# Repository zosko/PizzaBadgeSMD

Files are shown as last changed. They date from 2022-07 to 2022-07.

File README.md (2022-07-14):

# Pizza Badge

8 Slices pizza badge presented with LEDs. Slices will light when they receive response from server how many points you have.

## Scheme
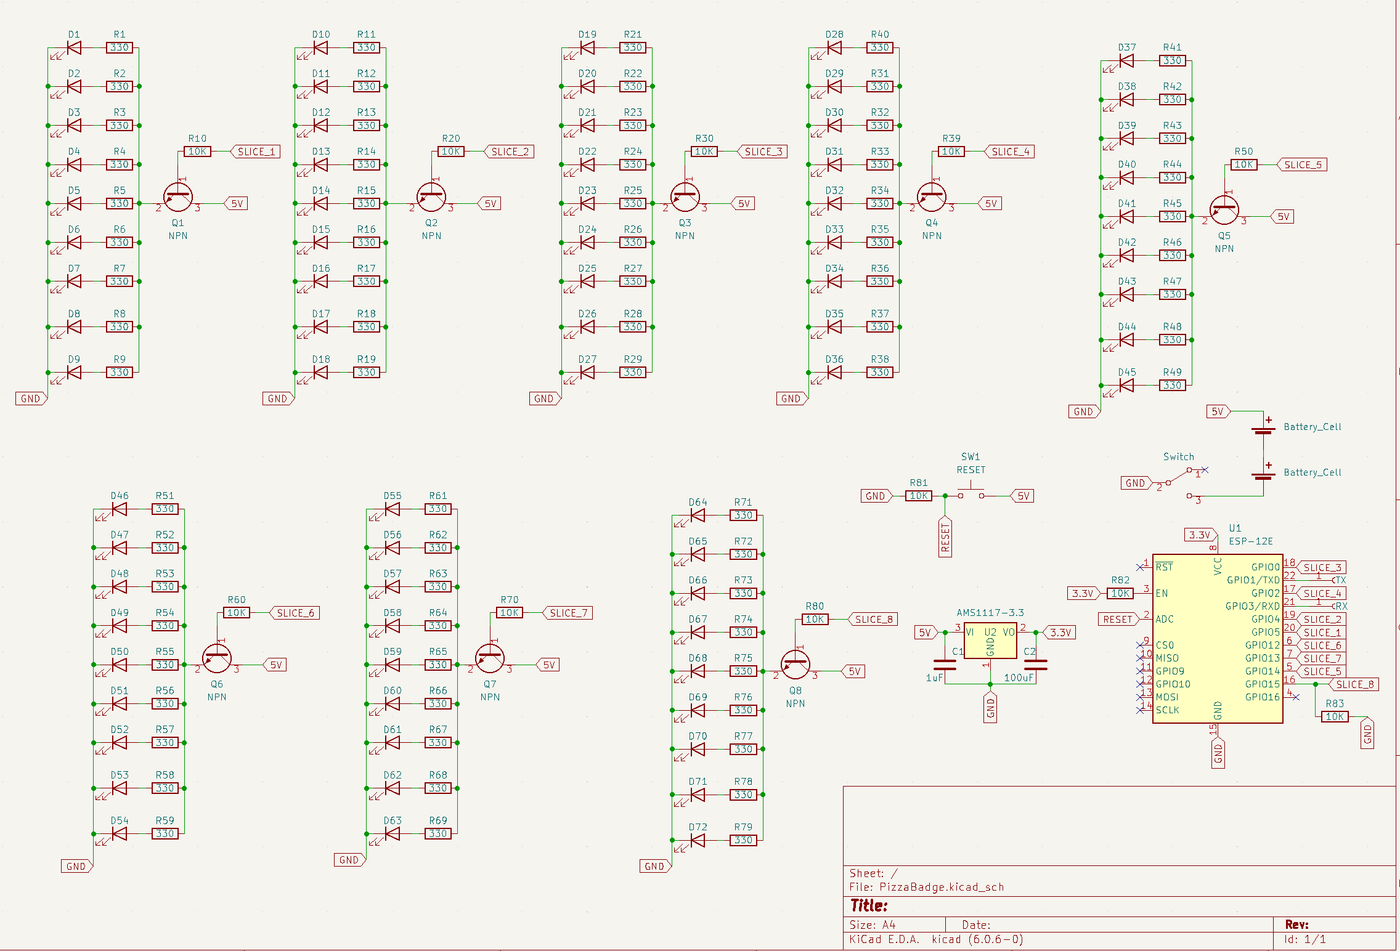
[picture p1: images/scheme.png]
Scheme


## Board
Board

## PCB Design

For PCB design i will use services from SeeedFusion. 

Seeed Fusion PCB Assembly Service offers one-stop prototyping for PCB manufacture, PCB assembly and as a result they produce superior quality PCBs and Fast Turnkey PCBA from 7 working days. When you prototype with Seeed Fusion, they can definitely provide Free DFA and Free functional tests for you! 

Check out their website to know about their manufacturing capabilities and service.
https://www.seeedstudio.com/prototype-pcb-assembly.html 

## Reasons to choose Seeed Studio
- They provide PCB services at extremely low pricing and with excellent quality.
- Their offer is structured in such a way that everyone may have these boards at a reasonable price.
- They have a highly knowledgeable crew that leads their clients to avail deals and guides them about the costs and rates of different services.
- A four-layer board with a comparable feature costs $5 for 10 pieces and is made in four days.
- SMT stencil with size (10cm x 13cm) is available for $8.00 per piece.

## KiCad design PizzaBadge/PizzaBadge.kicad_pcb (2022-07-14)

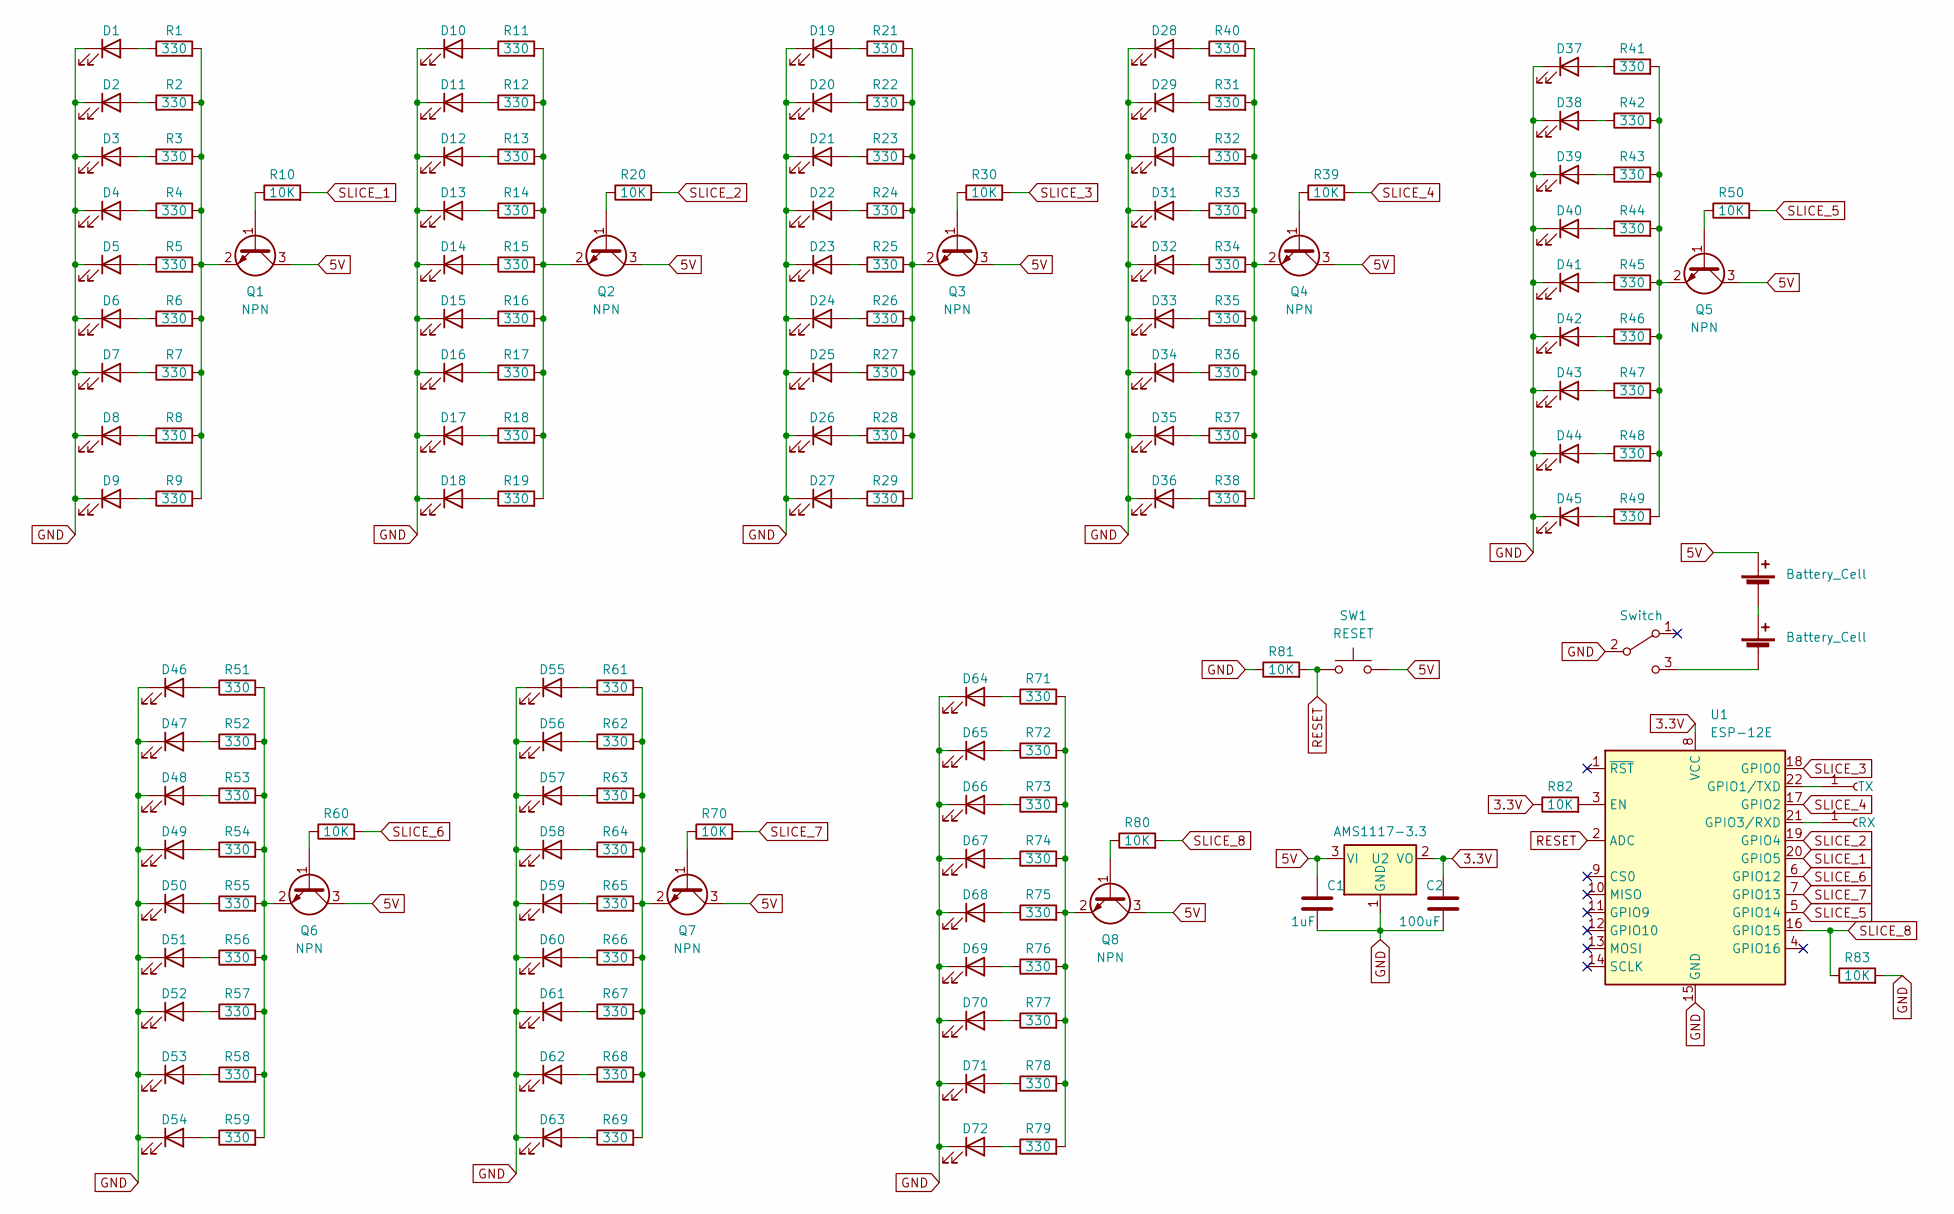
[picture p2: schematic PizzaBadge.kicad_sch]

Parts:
BT1, BT2: Battery_Cell; BatteryHolder_Keystone_3000_1x12mm
C1: 1uF; C_0805_2012Metric
C2: 100uF; C_0805_2012Metric
D1, D2, D3, D4, D5, D6, D7, D8, D9, D10, D11, D12, D13, D14, D15, D16, D17, D18, D19, D20, D21, D22, D23, D24, D25, D26, D27, D28, D29, D30, D31, D32, D33, D34, D35, D36, D37, D38, D39, D40, D41, D42, D43, D44, D45, D46, D47, D48, D49, D50, D51, D52, D53, D54, D55, D56, D57, D58, D59, D60, D61, D62, D63, D64, D65, D66, D67, D68, D69, D70, D71, D72: LED; LED_0805_2012Metric
J1: TX; TestPoint_Pad_2.0x2.0mm
J2: RX; TestPoint_Pad_2.0x2.0mm
Q1, Q2, Q3, Q4, Q5, Q6, Q7, Q8: NPN; SOT-23
R1, R2, R3, R4, R5, R6, R7, R8, R9, R11, R12, R13, R14, R15, R16, R17, R18, R19, R21, R22, R23, R24, R25, R26, R27, R28, R29, R31, R32, R33, R34, R35, R36, R37, R38, R40, R41, R42, R43, R44, R45, R46, R47, R48, R49, R51, R52, R53, R54, R55, R56, R57, R58, R59, R61, R62, R63, R64, R65, R66, R67, R68, R69, R71, R72, R73, R74, R75, R76, R77, R78, R79: 330; R_0805_2012Metric
R10, R20, R30, R39, R50, R60, R70, R80, R81, R82, R83: 10K; R_0805_2012Metric
SW1: RESET; SW_SPST_CK_RS282G05A3
SW2: Switch; SW_SPDT_PCM12
U1: ESP-12E
U2: AMS1117-3.3; SOT-223-3_TabPin2

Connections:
3.3V: C2.1, R82.1, U1.8 (VCC), U2.2 (VO)
5V: BT1.1 (+), C1.1, Q1.3 (C), Q2.3 (C), Q3.3 (C), Q4.3 (C), Q5.3 (C), Q6.3 (C), Q7.3 (C), Q8.3 (C), SW1.2, U2.3 (VI)
GND: C1.2, C2.2, D1.1 (K), D2.1 (K), D3.1 (K), D4.1 (K), D5.1 (K), D6.1 (K), D7.1 (K), D8.1 (K), D9.1 (K), D10.1 (K), D11.1 (K), D12.1 (K), D13.1 (K), D14.1 (K), D15.1 (K), D16.1 (K), D17.1 (K), D18.1 (K), D19.1 (K), D20.1 (K), D21.1 (K), D22.1 (K), D23.1 (K), D24.1 (K), D25.1 (K), D26.1 (K), D27.1 (K), D28.1 (K), D29.1 (K), D30.1 (K), D31.1 (K), D32.1 (K), D33.1 (K), D34.1 (K), D35.1 (K), D36.1 (K), D37.1 (K), D38.1 (K), D39.1 (K), D40.1 (K), D41.1 (K), D42.1 (K), D43.1 (K), D44.1 (K), D45.1 (K), D46.1 (K), D47.1 (K), D48.1 (K), D49.1 (K), D50.1 (K), D51.1 (K), D52.1 (K), D53.1 (K), D54.1 (K), D55.1 (K), D56.1 (K), D57.1 (K), D58.1 (K), D59.1 (K), D60.1 (K), D61.1 (K), D62.1 (K), D63.1 (K), D64.1 (K), D65.1 (K), D66.1 (K), D67.1 (K), D68.1 (K), D69.1 (K), D70.1 (K), D71.1 (K), D72.1 (K), R81.1, R83.2, SW2.2 (B), U1.15 (GND), U2.1 (GND)
unnamed: BT1.2 (-), BT2.1 (+)
unnamed: BT2.2 (-), SW2.3 (C)
unnamed: D1.2 (A), R1.1
unnamed: D2.2 (A), R2.1
unnamed: D3.2 (A), R3.1
unnamed: D4.2 (A), R4.1
unnamed: D5.2 (A), R5.1
unnamed: D6.2 (A), R6.1
unnamed: D7.2 (A), R7.1
unnamed: D8.2 (A), R8.1
unnamed: D9.2 (A), R9.1
unnamed: D10.2 (A), R11.1
unnamed: D11.2 (A), R12.1
unnamed: D12.2 (A), R13.1
unnamed: D13.2 (A), R14.1
unnamed: D14.2 (A), R15.1
unnamed: D15.2 (A), R16.1
unnamed: D16.2 (A), R17.1
unnamed: D17.2 (A), R18.1
unnamed: D18.2 (A), R19.1
unnamed: D19.2 (A), R21.1
unnamed: D20.2 (A), R22.1
unnamed: D21.2 (A), R23.1
unnamed: D22.2 (A), R24.1
unnamed: D23.2 (A), R25.1
unnamed: D24.2 (A), R26.1
unnamed: D25.2 (A), R27.1
unnamed: D26.2 (A), R28.1
unnamed: D27.2 (A), R29.1
unnamed: D28.2 (A), R40.1
unnamed: D29.2 (A), R31.1
unnamed: D30.2 (A), R32.1
unnamed: D31.2 (A), R33.1
unnamed: D32.2 (A), R34.1
unnamed: D33.2 (A), R35.1
unnamed: D34.2 (A), R36.1
unnamed: D35.2 (A), R37.1
unnamed: D36.2 (A), R38.1
unnamed: D37.2 (A), R41.1
unnamed: D38.2 (A), R42.1
unnamed: D39.2 (A), R43.1
unnamed: D40.2 (A), R44.1
unnamed: D41.2 (A), R45.1
unnamed: D42.2 (A), R46.1
unnamed: D43.2 (A), R47.1
unnamed: D44.2 (A), R48.1
unnamed: D45.2 (A), R49.1
unnamed: D46.2 (A), R51.1
unnamed: D47.2 (A), R52.1
unnamed: D48.2 (A), R53.1
unnamed: D49.2 (A), R54.1
unnamed: D50.2 (A), R55.1
unnamed: D51.2 (A), R56.1
unnamed: D52.2 (A), R57.1
unnamed: D53.2 (A), R58.1
unnamed: D54.2 (A), R59.1
unnamed: D55.2 (A), R61.1
unnamed: D56.2 (A), R62.1
unnamed: D57.2 (A), R63.1
unnamed: D58.2 (A), R64.1
unnamed: D59.2 (A), R65.1
unnamed: D60.2 (A), R66.1
unnamed: D61.2 (A), R67.1
unnamed: D62.2 (A), R68.1
unnamed: D63.2 (A), R69.1
unnamed: D64.2 (A), R71.1
unnamed: D65.2 (A), R72.1
unnamed: D66.2 (A), R73.1
unnamed: D67.2 (A), R74.1
unnamed: D68.2 (A), R75.1
unnamed: D69.2 (A), R76.1
unnamed: D70.2 (A), R77.1
unnamed: D71.2 (A), R78.1
unnamed: D72.2 (A), R79.1
unnamed: Q1.1 (B), R10.1
unnamed: Q1.2 (E), R1.2, R2.2, R3.2, R4.2, R5.2, R6.2, R7.2, R8.2, R9.2
unnamed: Q2.1 (B), R20.1
unnamed: Q2.2 (E), R11.2, R12.2, R13.2, R14.2, R15.2, R16.2, R17.2, R18.2, R19.2
unnamed: Q3.1 (B), R30.1
unnamed: Q3.2 (E), R21.2, R22.2, R23.2, R24.2, R25.2, R26.2, R27.2, R28.2, R29.2
unnamed: Q4.1 (B), R39.1
unnamed: Q4.2 (E), R31.2, R32.2, R33.2, R34.2, R35.2, R36.2, R37.2, R38.2, R40.2
unnamed: Q5.1 (B), R50.1
unnamed: Q5.2 (E), R41.2, R42.2, R43.2, R44.2, R45.2, R46.2, R47.2, R48.2, R49.2
unnamed: Q6.1 (B), R60.1
unnamed: Q6.2 (E), R51.2, R52.2, R53.2, R54.2, R55.2, R56.2, R57.2, R58.2, R59.2
unnamed: Q7.1 (B), R70.1
unnamed: Q7.2 (E), R61.2, R62.2, R63.2, R64.2, R65.2, R66.2, R67.2, R68.2, R69.2
unnamed: Q8.1 (B), R80.1
unnamed: Q8.2 (E), R71.2, R72.2, R73.2, R74.2, R75.2, R76.2, R77.2, R78.2, R79.2
unnamed: R82.2, U1.3 (EN)
unnamed: J2.1, U1.21 (GPIO3/RXD)
unnamed: J1.1, U1.22 (GPIO1/TXD)
RESET: R81.2, SW1.1, U1.2 (ADC)
SLICE_1: R10.2, U1.20 (GPIO5)
SLICE_2: R20.2, U1.19 (GPIO4)
SLICE_3: R30.2, U1.18 (GPIO0)
SLICE_4: R39.2, U1.17 (GPIO2)
SLICE_5: R50.2, U1.5 (GPIO14)
SLICE_6: R60.2, U1.6 (GPIO12)
SLICE_7: R70.2, U1.7 (GPIO13)
SLICE_8: R80.2, R83.1, U1.16 (GPIO15)

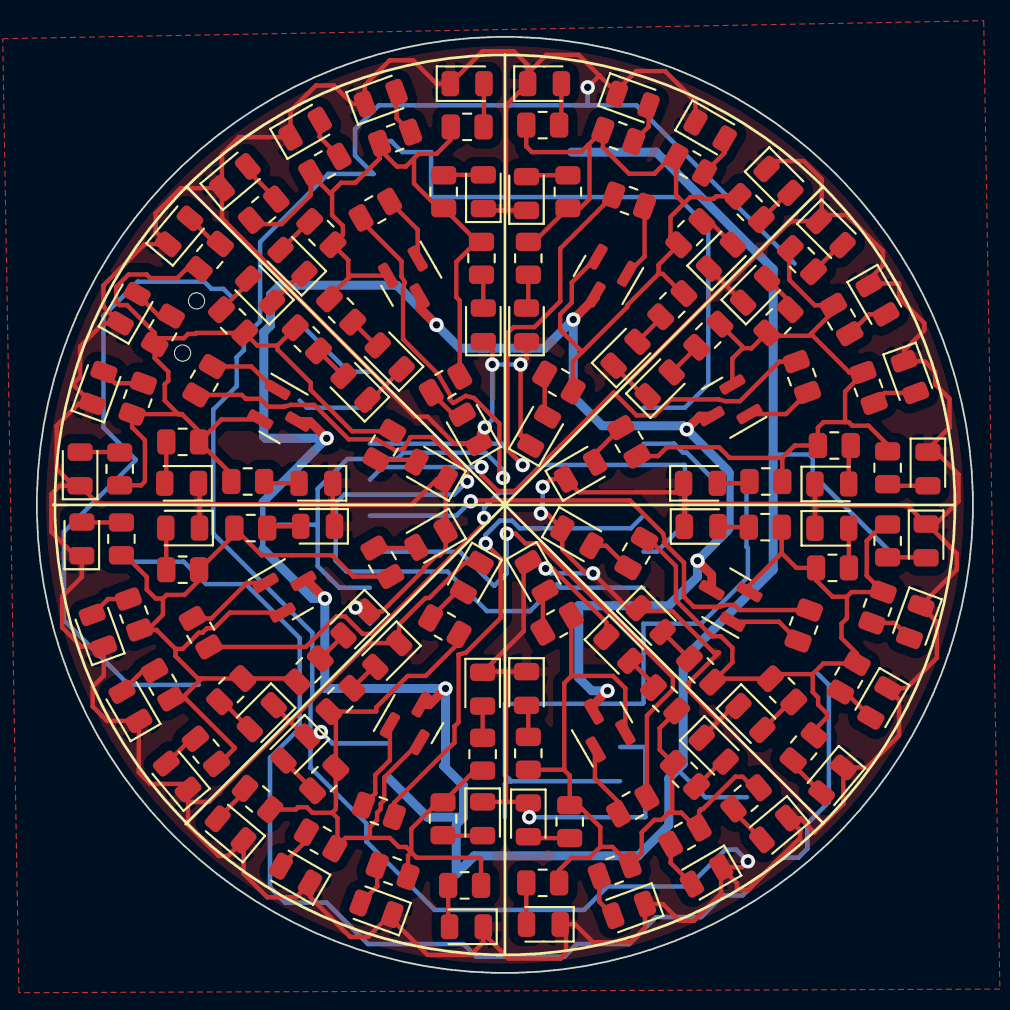
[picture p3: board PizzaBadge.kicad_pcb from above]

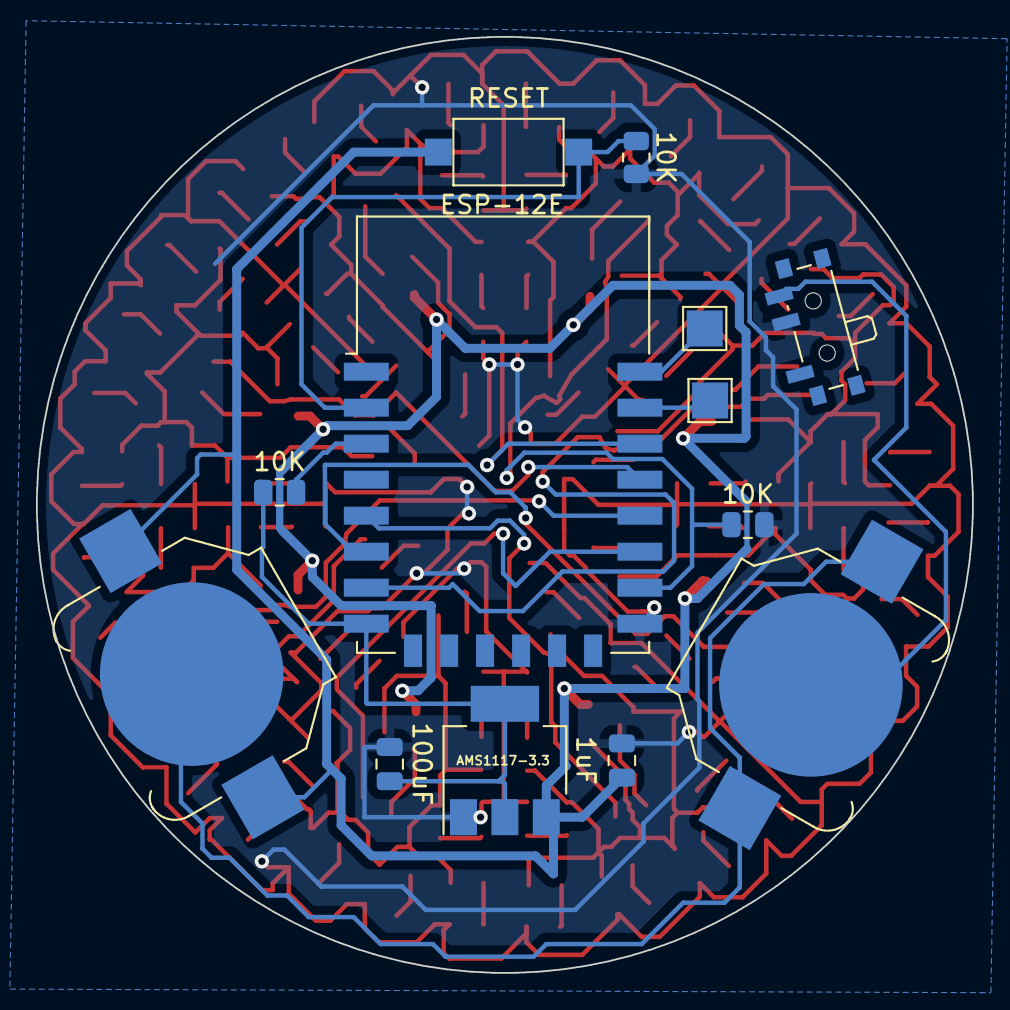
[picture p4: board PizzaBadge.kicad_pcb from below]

Board: 2 copper layers, 52.0 x 52.0 mm, 173 parts (13 on the bottom side), 105 nets.

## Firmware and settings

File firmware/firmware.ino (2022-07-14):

#include <WiFiManager.h>
#include <EEPROM.h>
#include <ESP8266HTTPClient.h>

const int pin_reset = A0;
const int pin_slice_1 = D1;
const int pin_slice_2 = D2;
const int pin_slice_3 = D3;
const int pin_slice_4 = D4;
const int pin_slice_5 = D5;
const int pin_slice_6 = D6;
const int pin_slice_7 = D7;
const int pin_slice_8 = D8;

const int allPins[8] = { pin_slice_1, pin_slice_2, pin_slice_3, pin_slice_4,
                         pin_slice_5, pin_slice_6, pin_slice_7, pin_slice_8
                       };

WiFiManager wm;
WiFiManagerParameter custom_field;
bool shouldSaveConfig = false;
String webURLParam = "";

void setup() {
  Serial.begin(115200);
  EEPROM.begin(512);
  WiFi.mode(WIFI_STA);

  for (int i = 0; i < 8; i++) {
    pinMode(allPins[i], OUTPUT);
  }
  turnOffAll();

  wm.setTitle("Pizza Badge");

  const char* custom_server_str = "<br/><label for='customfieldid'>Enter Email</label><input type='text' name='customfieldid'>";
  new (&custom_field) WiFiManagerParameter(custom_server_str);
  wm.addParameter(&custom_field);
  wm.setSaveParamsCallback(saveParamCallback);

  std::vector<const char *> wm_menu  = {"wifi"};
  wm.setShowInfoUpdate(false);
  wm.setShowInfoErase(false);
  wm.setMenu(wm_menu);

  bool res;
  res = wm.autoConnect("PizzaBadgeAP");

  if (!res) {
    Serial.println("Failed to connect");
  }
  else {
    Serial.println("connected...yeey :)");
    if (shouldSaveConfig) {
      writeCodeToEEPROM(webURLParam);
      delay(100);
    }
    webURLParam = readCodeFromEEPROM();
    delay(100);
    Serial.print("LOADED FROM EEPROM:[");
    Serial.print(webURLParam);
    Serial.println("]");
  }

  pinMode(pin_reset, INPUT_PULLUP);
}

void loop() {
  checkForPizzaPoint();
  delay(5000);

  // SMD version > 1000
  // Normal version < 1000
  if (analogRead(pin_reset) > 1000) { 
    animateReset();
    factoryReset();
  }
}

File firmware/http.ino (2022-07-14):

void checkForPizzaPoint() {
  WiFiClient client;
  HTTPClient http;
  if (http.begin(client, "http://192.168.31.86:8080/check/" + webURLParam)) {
    int httpCode = http.GET();
    if (httpCode > 0) {
      if (httpCode == HTTP_CODE_OK) {
        String payload = http.getString();
        Serial.print("Payload:");
        Serial.println(payload);
        if (payload == "random-eat") {
          animateProp();
        }
        else if (payload == "free-pizza") {
          freePizzaAnimate();
          animateRotation();
          animateSlice(8);
        }
        else if (payload.toInt() > 0 && payload.toInt() < 9) {
          turnOffAll();
          animateReset();
          animateRotation();
          animateSlice(payload.toInt());
        }
      }
    } else {
      Serial.printf("[HTTP] failed, error: %s\n", http.errorToString(httpCode).c_str());
    }
    http.end();
  }
}
